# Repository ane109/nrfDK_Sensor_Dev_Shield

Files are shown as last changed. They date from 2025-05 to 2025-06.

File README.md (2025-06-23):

# nrfDK_Sensor_Dev_Shield
Sensor shield compatible with nRFDK and Arduino development boards

## Details
- Test platform for sensors intended for use on an IoT wearable
- Interfaces directly with an nRF9160DK development board over I2C
- Contains a heart rate monitor, 9-DOF IMU, and coulomb counter with reversible current
- Test points for all signals and voltages

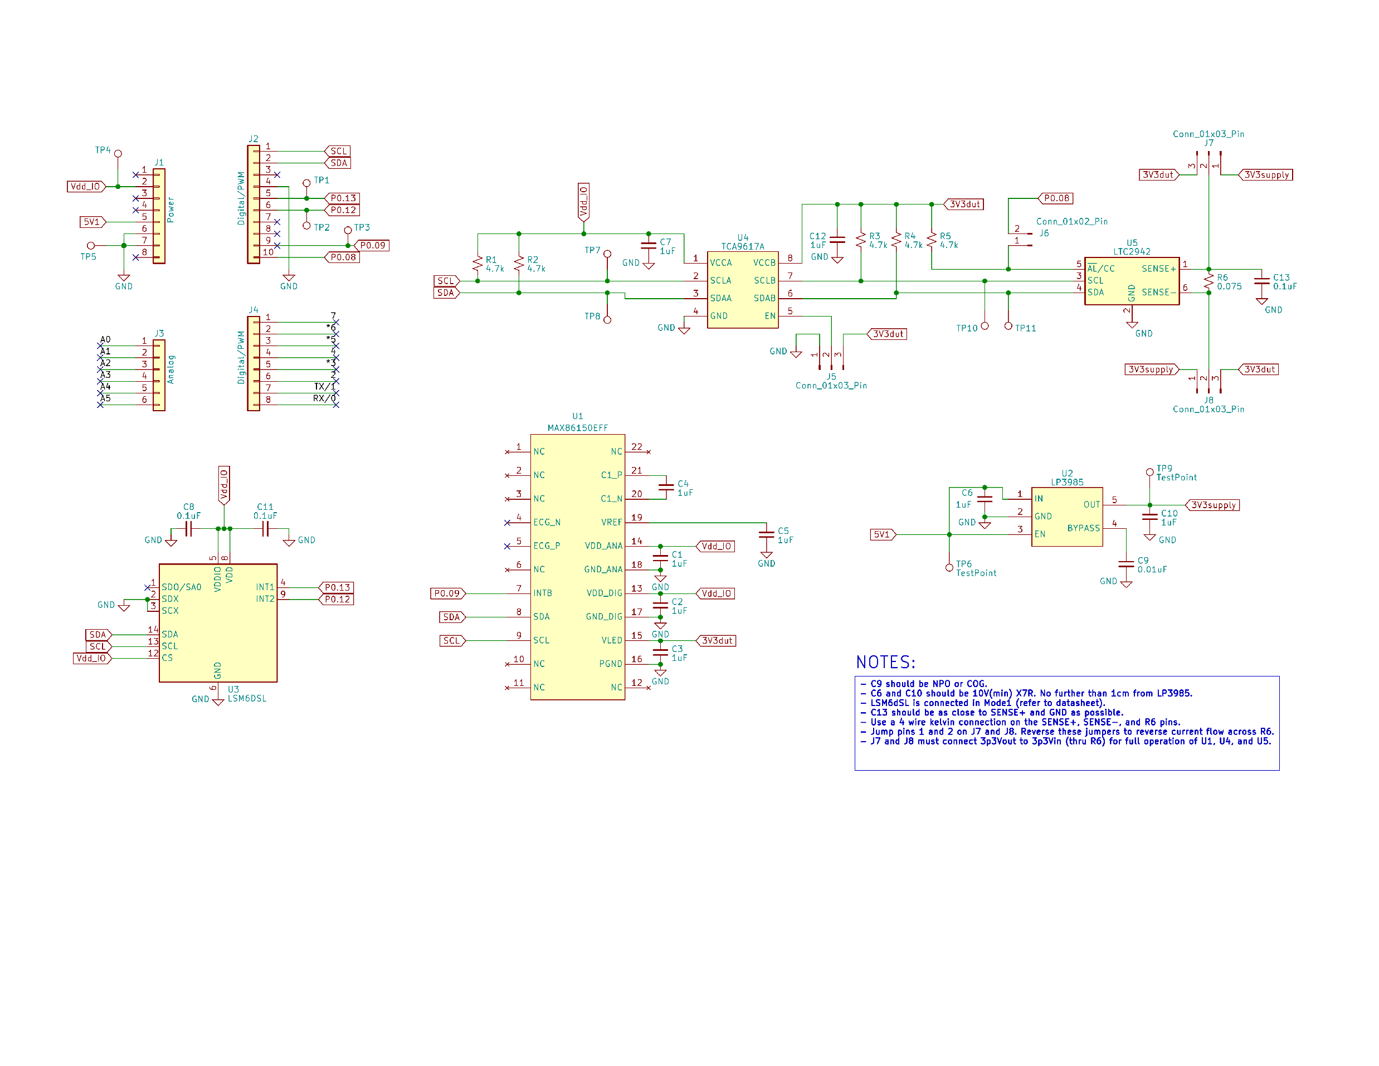
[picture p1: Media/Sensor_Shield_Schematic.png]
Schematic and design notes


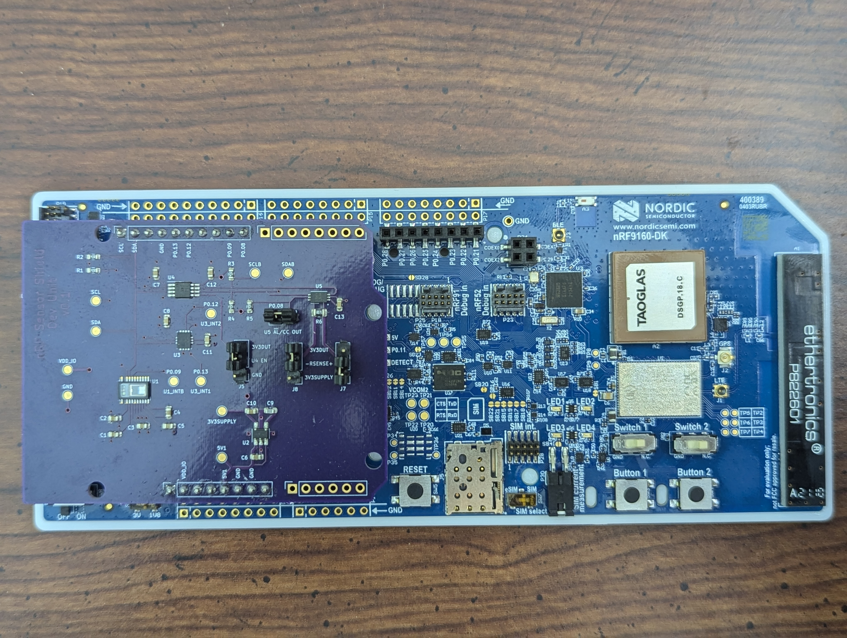
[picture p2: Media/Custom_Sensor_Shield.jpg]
Custom shield attached to an nRF9160DK


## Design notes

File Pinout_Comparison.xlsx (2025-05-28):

nrf52840dk | nrf9160dk |  | Uno | Uno |  | nrf9160dk | nrf52840dk
 |  |  |  | D19/SCL | o | P0.31 | P0.26
 |  |  |  | D18/SDA | o | P0.30 | P0.27
 |  |  |  | Aref | o | P0.20 | P0.02
 |  |  |  | GND | o | GND | GND
VDD | VDD | o | NC | D13 | o | P0.13 | P1.15
VDD | VDD | o | IOREF | D12 | o | P0.12 | P1.14
Reset | Reset | o | Reset | ~D11 | o | P0.11 | P1.13
VDD | VDD | o | +3v3 | ~D10 | o | P0.10 | P1.12
5V | 5V | o | +5V | ~D9 | o | P0.09 | P1.11
GND | GND | o | GND | D8 | o | P0.08 | P1.10
GND | GND | o | GND
NC | NC | o | Vin | D7 | o | P0.07 | P1.08
 |  |  |  | ~D6 | o | P0.06 | P1.07
P0.03 | P0.14 | o | A0/D14 | ~D5 | o | P0.05 | P1.06
P0.05 | P0.15 | o | A1/D15 | D4 | o | P0.04 | P1.05
P0.28 | P0.16 | o | A2/D16 | ~D3 | o | P0.03 | P1.04
P0.29 | P0.17 | o | A3/D17 | D2 | o | P0.02 | P1.03
P0.30 | P0.18 | o | A4/D18 | D1/TX | o | P0.01 | P1.02
P0.31 | P0.19 | o | A5/D19 | D1/RX | o | P0.00 | P1.01

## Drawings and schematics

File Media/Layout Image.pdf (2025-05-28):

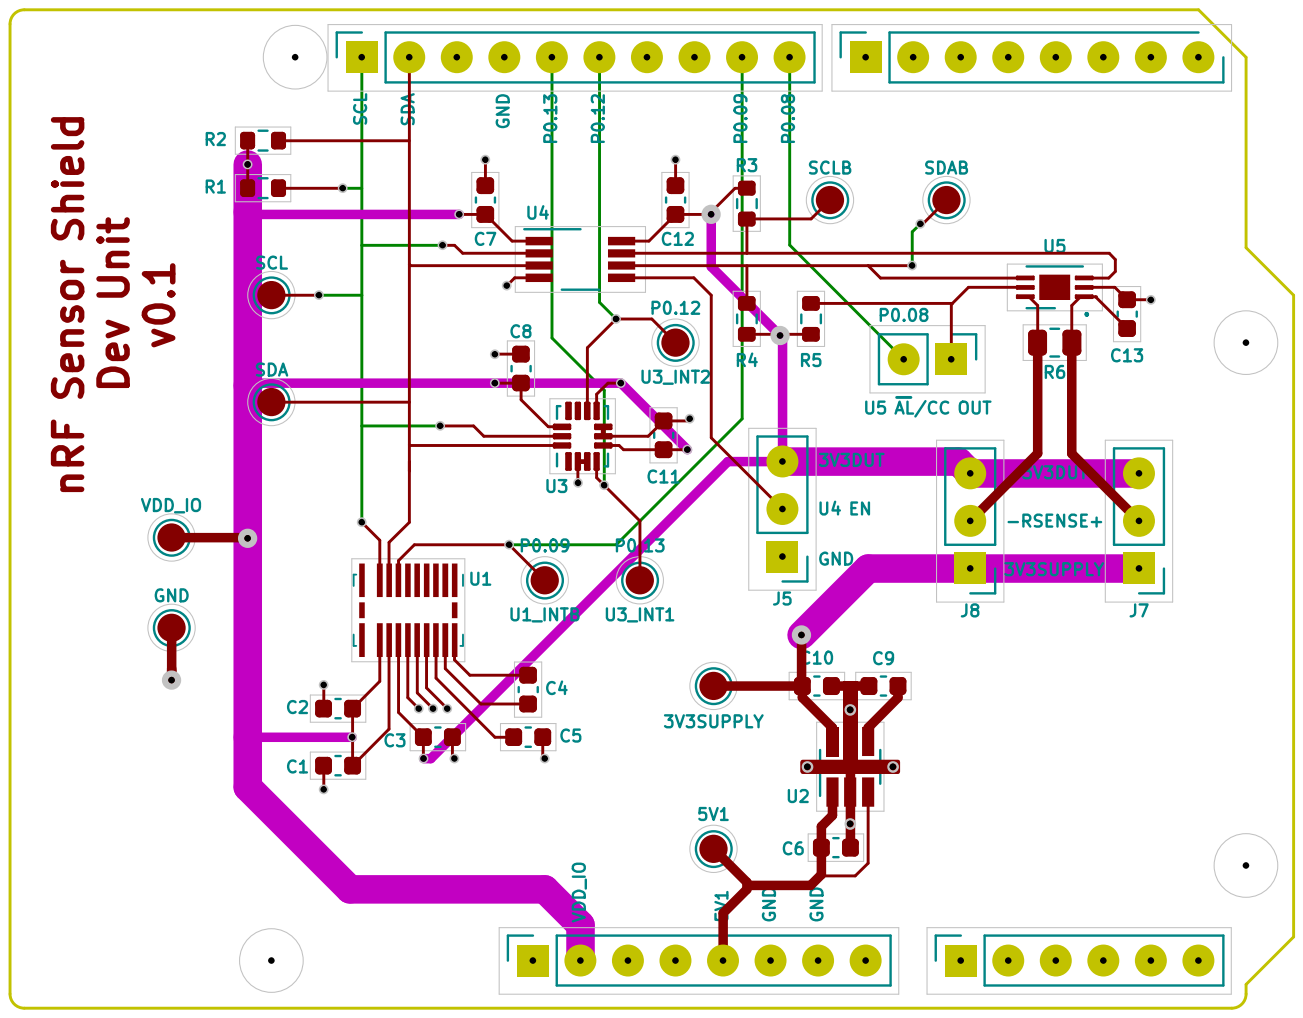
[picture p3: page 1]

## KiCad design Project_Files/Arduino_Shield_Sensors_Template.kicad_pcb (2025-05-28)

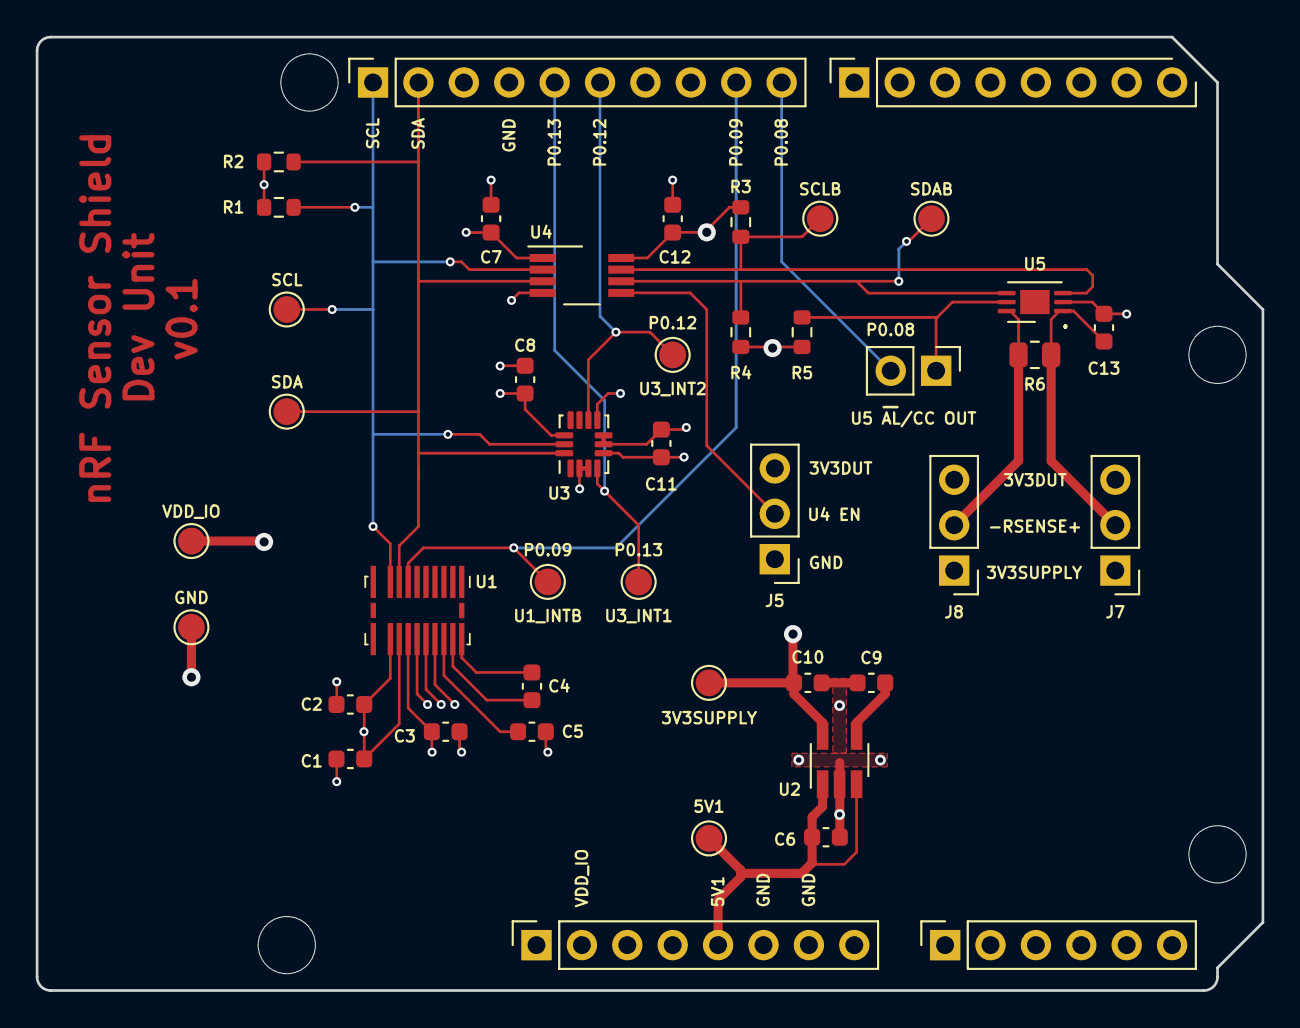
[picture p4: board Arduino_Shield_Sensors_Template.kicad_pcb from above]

Board: 4 copper layers, 68.6 x 53.3 mm, 47 parts (0 on the bottom side), 21 nets.

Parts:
3V3SUPPLY, 5V1: TestPoint; TestPoint_Pad_D1.5mm
C1, C2, C3, C4, C5, C6, C7, C10, C12: 1uF; C_0603_1608Metric
C8, C11, C13: 0.1uF; C_0603_1608Metric
C9: 0.01uF; C_0603_1608Metric
GND: TestPoint; TestPoint_Pad_D1.5mm
J1: Power; PinSocket_1x08_P2.54mm_Vertical
J2: Digital/PWM; PinSocket_1x10_P2.54mm_Vertical
J3: Analog; PinSocket_1x06_P2.54mm_Vertical
J4: Digital/PWM; PinSocket_1x08_P2.54mm_Vertical
J5, J7, J8: Conn_01x03_Pin; PinHeader_1x03_P2.54mm_Vertical
MH1, MH2, MH3, MH4: MountingHole_3.2mm
R1, R2, R3, R4, R5: 4.7k; R_0603_1608Metric
R6: 0.075; R_0805_2012Metric
SCL: TestPoint; TestPoint_Pad_D1.5mm
SCLB: TestPoint; TestPoint_Pad_D1.5mm
SDA: TestPoint; TestPoint_Pad_D1.5mm
SDAB: TestPoint; TestPoint_Pad_D1.5mm
U1: MAX86150EFF; MAX86150_extended
U1_INTB, U3_INT1, U3_INT2: TestPoint; TestPoint_Pad_D1.5mm
U2: LP3985; SOT-23-5_HandSoldering
U3: LSM6DSL; LSM6DSL_extended
U4: TCA9617A; VSSOP-8_3.0x3.0mm_P0.65mm
U5: LTC2942; LTC2942_Extended
U5 AL/CC OUT: Conn_01x02_Pin; PinHeader_1x02_P2.54mm_Vertical
VDD_IO: TestPoint; TestPoint_Pad_D1.5mm

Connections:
3V3dut: C3.2, C12.1, J5.3, J7.3, J8.3, R3.1, R4.1, R5.1, U1.15 (VLED), U4.8 (VCCB)
3V3supply: 3V3SUPPLY.1, C10.1, J7.1, J8.1, U2.5 (OUT)
5V1: 5V1.1, C6.1, J1.5, U2.1 (IN), U2.3 (EN)
GND: C1.1, C2.1, C3.1, C5.1, C6.2, C7.2, C8.1, C9.2, C10.2, C11.2, C12.2, C13.1, GND.1, J1.6, J1.7, J2.4, J5.1, U1.16 (PGND), U1.17 (GND_DIG), U1.18 (GND_ANA), U2.2 (GND), U3.2 (SDX), U3.3 (SCX), U3.6 (GND), U3.7 (GND), U4.4 (GND), U5.2 (GND)
unnamed: J5.2, U4.5 (EN)
unnamed: R5.2, U5.5 (~AL/CC), U5 AL/CC OUT.1
unnamed: C13.2, J7.2, R6.1, U5.1 (SENSE+)
unnamed: J8.2, R6.2, U5.6 (SENSE-)
unnamed: C4.1, U1.20 (C1_N)
unnamed: C4.2, U1.21 (C1_P)
unnamed: C5.2, U1.19 (VREF)
unnamed: C9.1, U2.4 (BYPASS)
unnamed: R3.2, SCLB.1, U4.7 (SCLB), U5.3 (SCL)
unnamed: R4.2, SDAB.1, U4.6 (SDAB), U5.4 (SDA)
P0.08: J2.10, U5 AL/CC OUT.2
P0.09: J2.9, U1.7 (INTB), U1_INTB.1
P0.12: J2.6, U3.9 (INT2), U3_INT2.1
P0.13: J2.5, U3.4 (INT1), U3_INT1.1
SCL: J2.1, R1.2, SCL.1, U1.9 (SCL), U3.13 (SCL), U4.2 (SCLA)
SDA: J2.2, R2.2, SDA.1, U1.8 (SDA), U3.14 (SDA), U4.3 (SDAA)
Vdd_IO: C1.2, C2.2, C7.1, C8.2, C11.1, J1.2, R1.1, R2.1, U1.13 (VDD_DIG), U1.14 (VDD_ANA), U3.5 (VDDIO), U3.8 (VDD), U3.12 (CS), U4.1 (VCCA), VDD_IO.1

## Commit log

2025-05-28 Added files
    Design notes and images added.
    [Pinout_Comparison.xlsx]
2025-06-23 Organized Files into appropriate folders
    [Arduino_Shield_Sensors_Template.kicad_pcb, Arduino_Shield_Sensors_Template.kicad_sch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]
2025-06-23 Update README.md
    Added project details, schematic, and photo
